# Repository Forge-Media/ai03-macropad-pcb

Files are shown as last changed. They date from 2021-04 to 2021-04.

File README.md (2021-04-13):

# ai03 Inspired Macropad PCB

My attempt at learning and implementing ai03's guide to pcb design for keyboards. The aim of this project is to design and manufacture a simple 3by3 MX style macropad pcb, which actually works. The pcb can then be manufactured and either assembled by hand or by the manufacturer if they provide assembly service.

## Project requirements:

- 9 1U MX-Hotswap switches
- USB-C support
- Atmega32u4 support (MU QFN-44 version)
- Per-key RGB LED (9 LEDs)
- RGB Underglow (4 LEDs)
- ESD and Reverse Bias protection (Fused VCC and +5v)
- QMK support
- VIA support (TBD)

## CAD

KiCad 5.1.9 is used for the pcb design, based on [ai03's guide](https://wiki.ai03.com/books/pcb-design).

**Required KiCad libraries:**

- [ai03's KiCad Type-C library](https://github.com/ai03-2725/Type-C.pretty) (USB-C 2.0 connector)
- [ai03's hybrid footprints](https://github.com/ai03-2725/MX_Alps_Hybrid/tree/master/MX_Only.pretty) (Kailh Hotswap footprints)
- [ai03's random components](https://github.com/ai03-2725/random-keyboard-parts.pretty) (Reset button footprint)
- [ebastler's kicad components](https://github.com/ebastler/kicad-keyboard-parts.pretty) (RGB LEDs footprints and 3D models)

**Optional KiCad libraries:**

- [KiCad included switches](https://kicad.github.io/footprints/Button_Switch_Keyboard) (Solder MX footprints) (Unless 5.1.9 or later)
- [Perigoso's KiCad Keyboard libraries](https://github.com/perigoso/keyswitch-kicad-library) (Alternative MX footprints)
- (TBD)

Autocad, Rhino and Fusion 360 are used for the case design.

## References:

- [ai03's - pcb guide](https://wiki.ai03.com/books/pcb-design)
- [ai03's KiCad library list](https://wiki.ai03.com/books/pcb-design/page/list-of-kicad-keyboard-parts-libraries)
- [33C Discord](https://discord.gg/6fHK4uk)
- [Keyboard Atelier Discord](https://discord.gg/b7vwhHS)
- [QMK Docs](https://beta.docs.qmk.fm/developing-qmk/c-development/compatible_microcontrollers)
- [Hadi's - PCB design series](https://www.youtube.com/channel/UCpWGAJr2AU7LPUwVYbBQZRg/playlists) (Incomplete!)
- [KoBuss' - How we designed a mechanicial keyboard pcb](https://www.youtube.com/watch?v=ezk02GJ9iMs)
- [MrKeebs' - PCB from Scratch with Gondo series](https://www.youtube.com/watch?v=Nk0egpDFqRA)
- [FJ Laboratories Blog](https://www.fjlaboratories.com/)
- (TBD)

## License

MIT License

Copyright (c) 2021 ForgeMedia (Jeremy Paton)

Permission is hereby granted, free of charge, to any person obtaining a copy of this hardware, software, and associated documentation files (the "Product"), to deal in the Product without restriction, including without limitation the rights to use, copy, modify, merge, publish, distribute, sublicense, and/or sell copies of the Product, and to permit persons to whom the Product is furnished to do so, subject to the following conditions:

The above copyright notice and this permission notice shall be included in all copies or substantial portions of the Product.

THE PRODUCT IS PROVIDED "AS IS", WITHOUT WARRANTY OF ANY KIND, EXPRESS OR IMPLIED, INCLUDING BUT NOT LIMITED TO THE WARRANTIES OF MERCHANTABILITY, FITNESS FOR A PARTICULAR PURPOSE AND NONINFRINGEMENT. IN NO EVENT SHALL THE AUTHORS OR COPYRIGHT HOLDERS BE LIABLE FOR ANY CLAIM, DAMAGES OR OTHER LIABILITY, WHETHER IN AN ACTION OF CONTRACT, TORT OR OTHERWISE, ARISING FROM, OUT OF OR IN CONNECTION WITH THE PRODUCT OR THE USE OR OTHER DEALINGS IN THE PRODUCT.

## For the Keyboard Community

You can produce and sell this keyboard design. ForgeMedia (Jeremy Paton) is not liable. Creator attribution is required however, no use of the creator's or 3rd party branding may be utilised in a derivative. This includes logos and brand names.

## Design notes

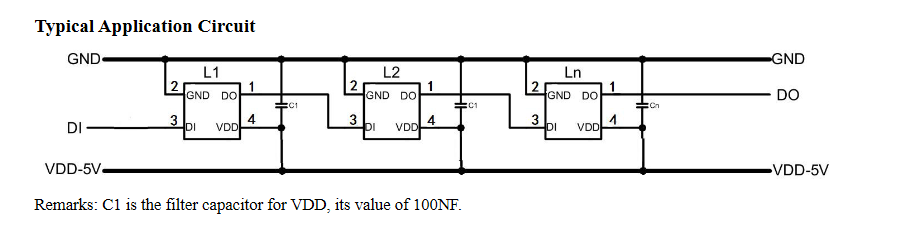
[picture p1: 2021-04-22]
references/specifications/String_RGB_LED_Array_Schematic.png

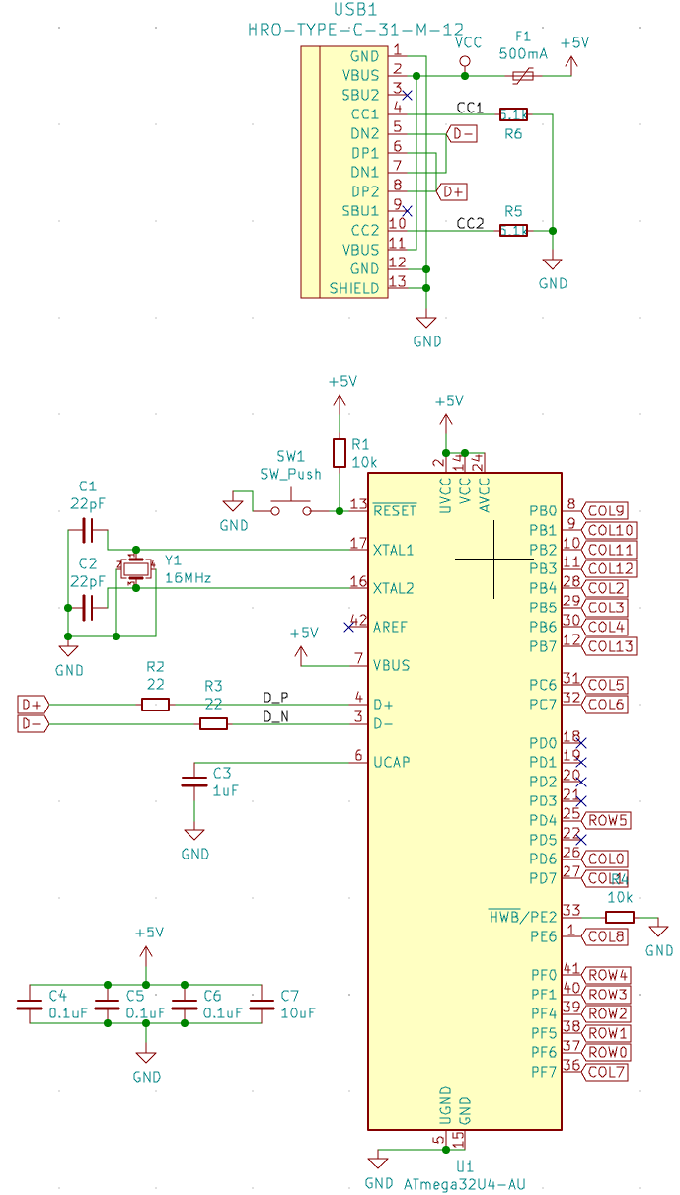
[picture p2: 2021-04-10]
references/reference_images/USB_Type-C_simplified_schematic_alt_2.png

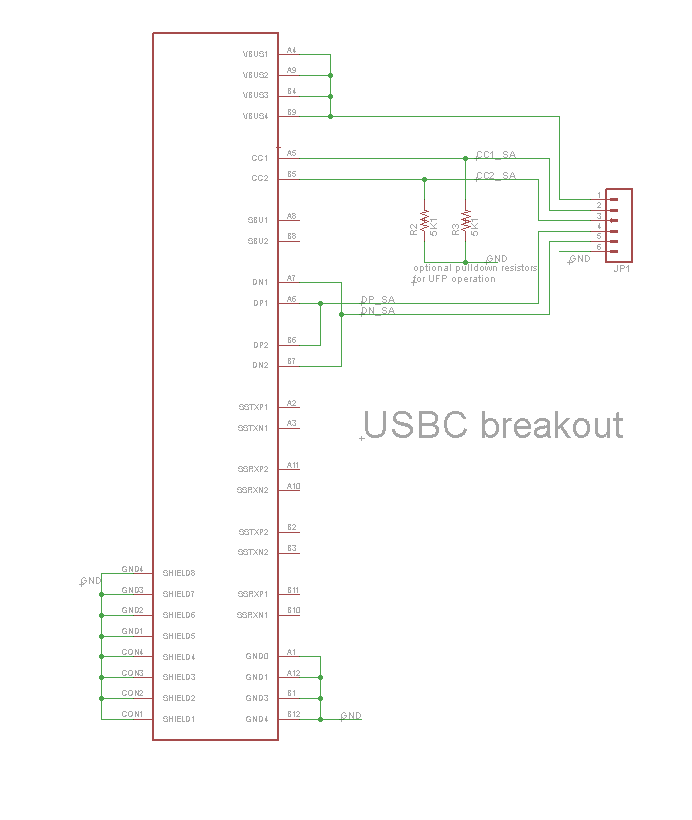
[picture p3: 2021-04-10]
references/reference_images/USB_Type-C_schematic.png

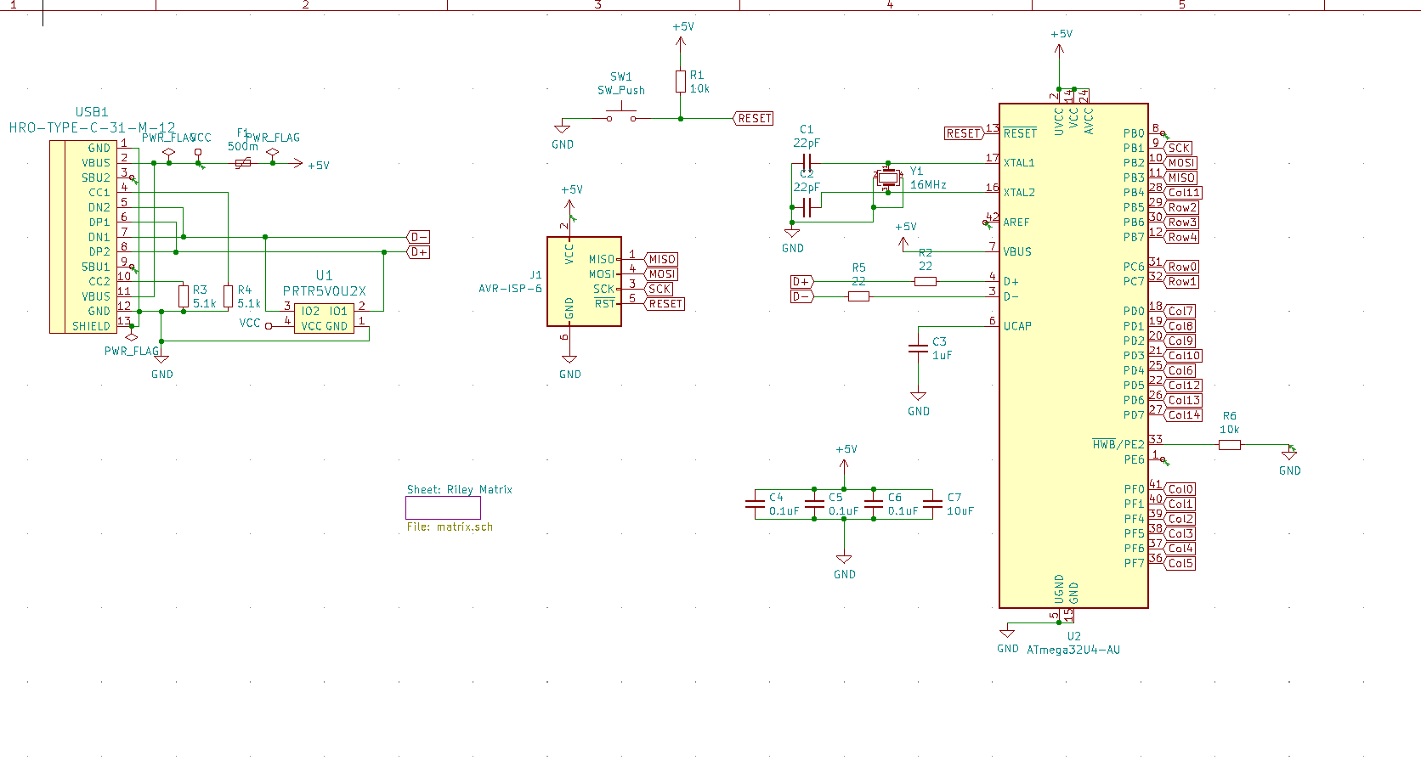
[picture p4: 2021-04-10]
references/reference_images/USB_Type-C_simplified_schematic_alt.png

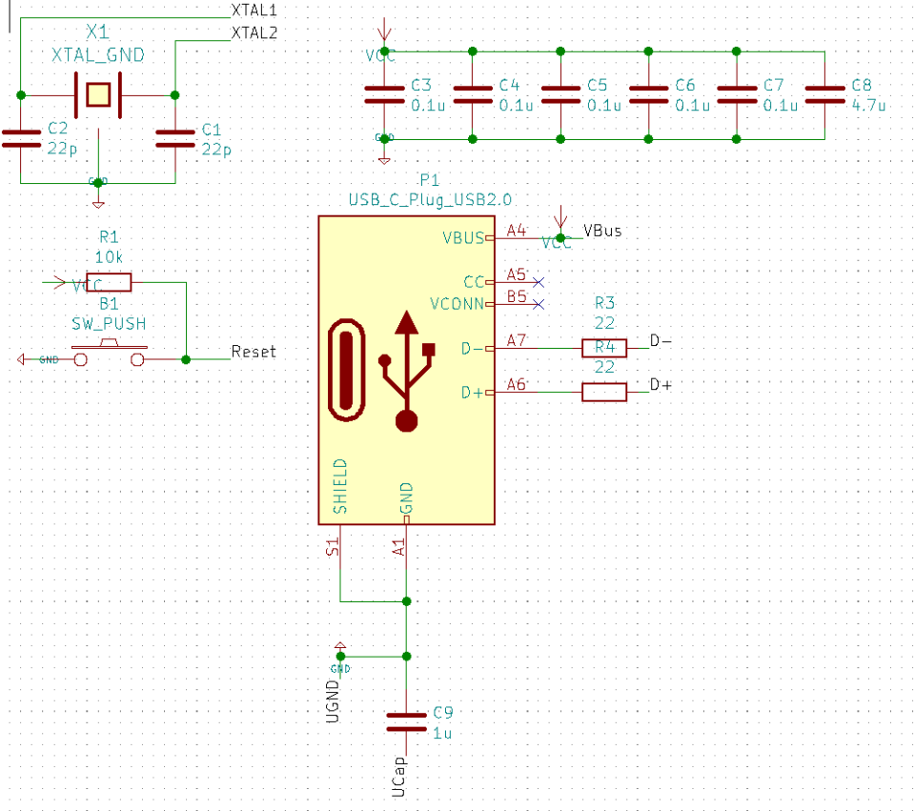
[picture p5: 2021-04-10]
references/reference_images/USB_Type-C_simplified_schematic.png

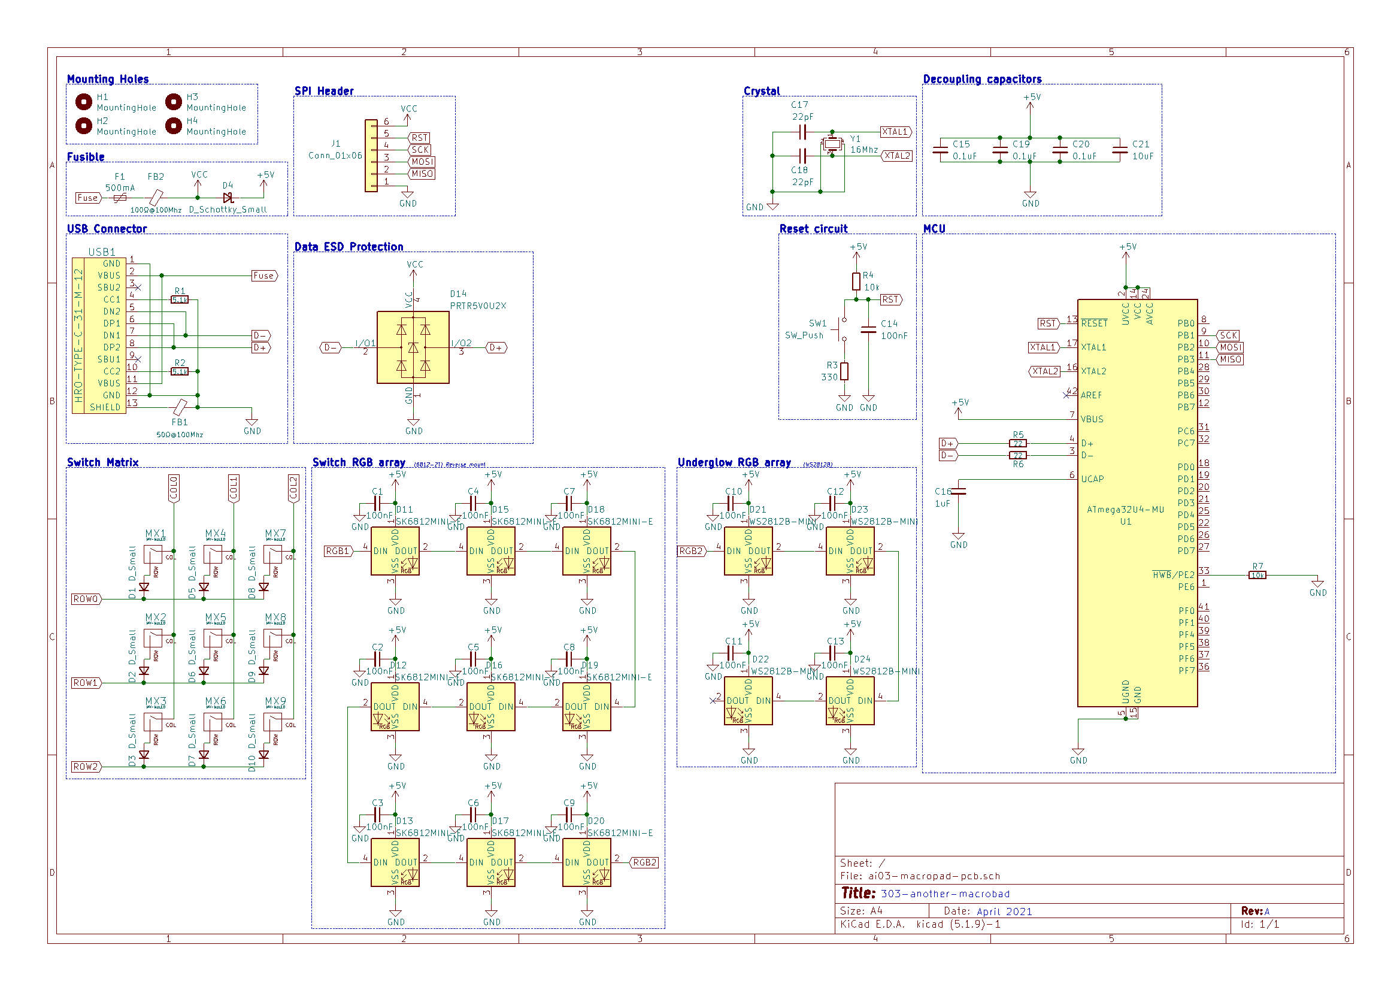
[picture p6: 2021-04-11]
references/schematic_reviews/schematic_rev_a.png

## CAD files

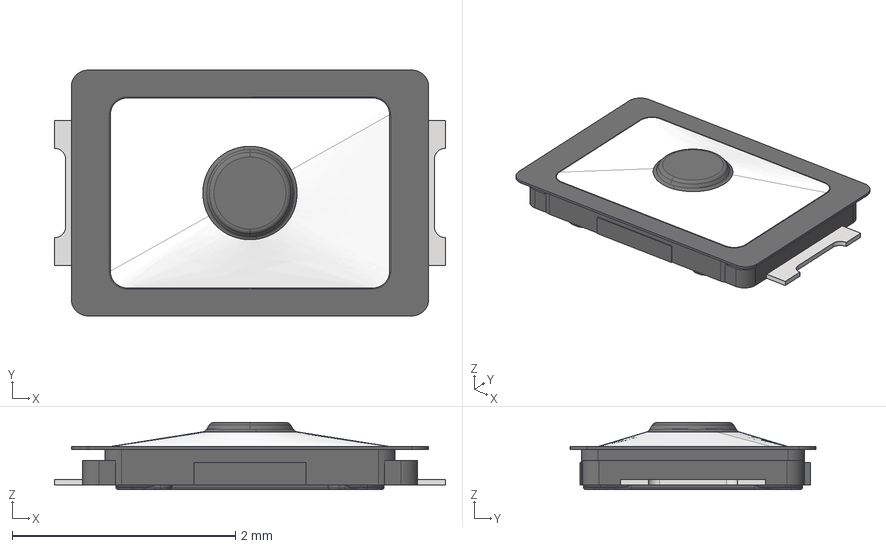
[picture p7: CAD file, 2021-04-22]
3D_models/EVPAWBD40_Solid.step
3.50 x 2.20 x 0.6 mm

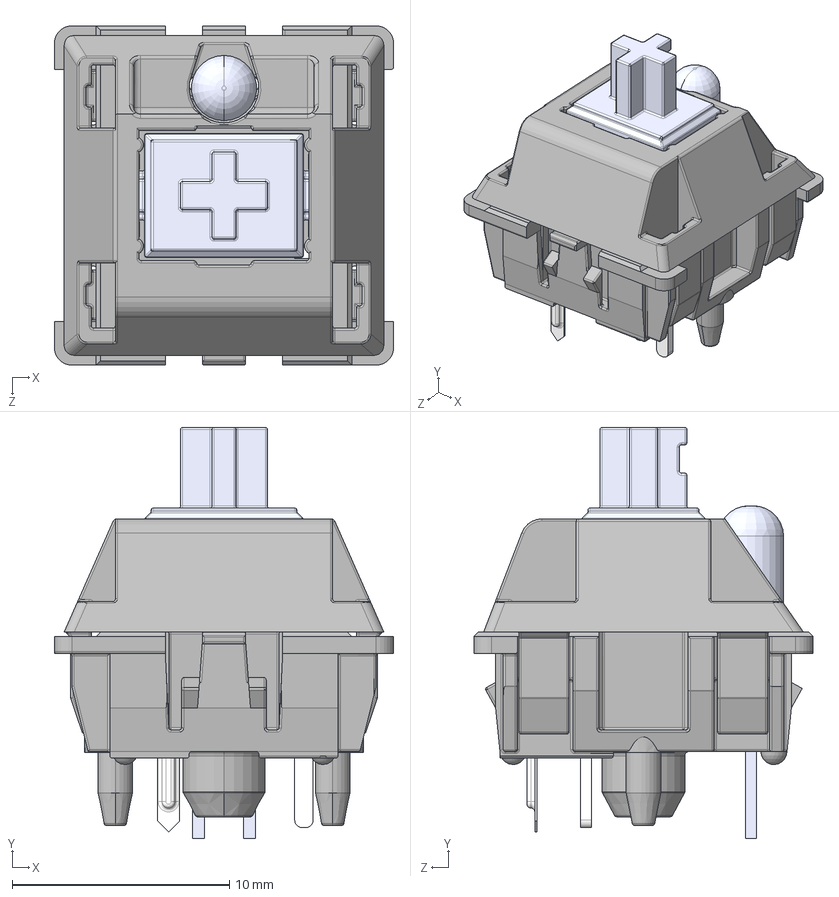
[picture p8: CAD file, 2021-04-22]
3D_models/MX.STEP
15.6 x 18.9 x 15.6 mm
MX 轴 按键′_ü___¨1
MX 轴 轴体áì_¨￠¨__
MX粣 拸簽LEDLEDLED
MX轴 轴体 底部 μ×2__默认_á2____è_
针脚___默认__è_

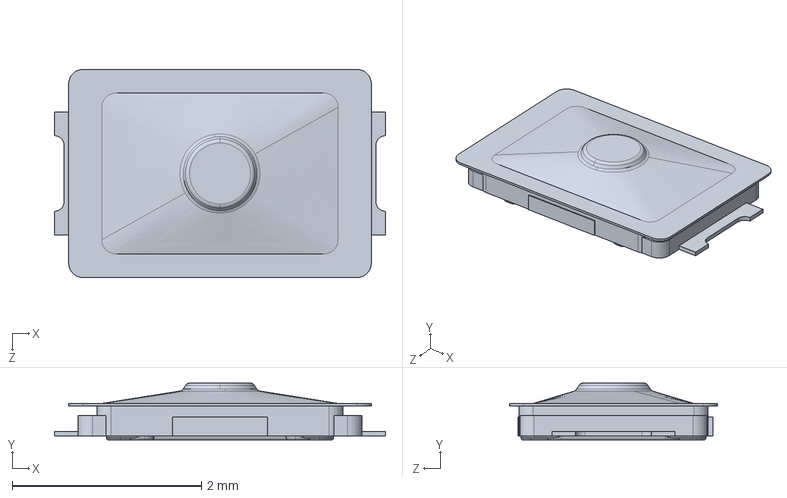
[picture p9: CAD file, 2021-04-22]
3D_models/EVPAWBD40.step
3.50 x 0.6 x 2.20 mm

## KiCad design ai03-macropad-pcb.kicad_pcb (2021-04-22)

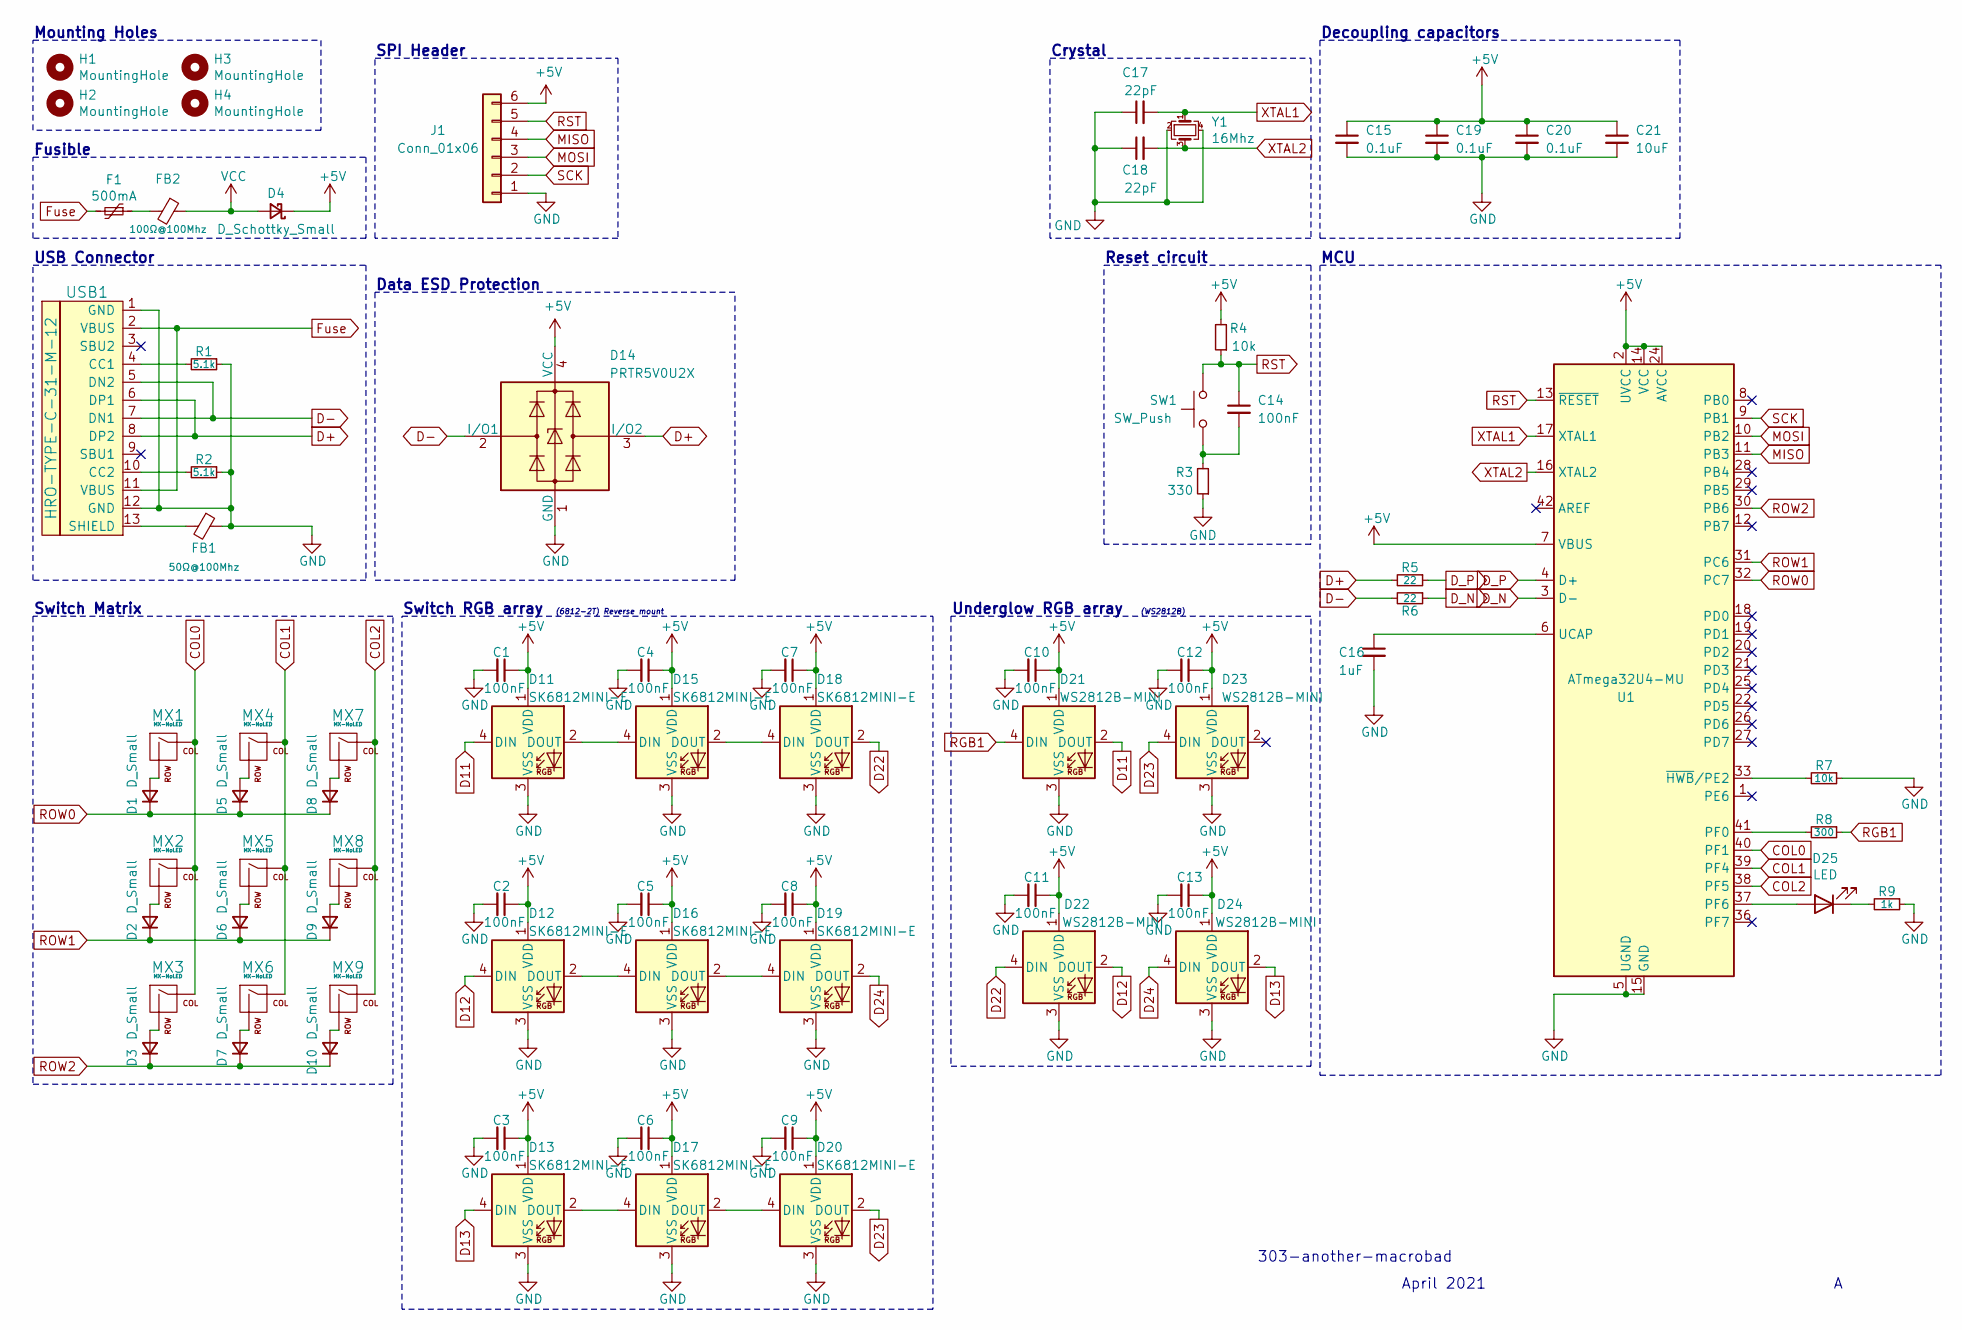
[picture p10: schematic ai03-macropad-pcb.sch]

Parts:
C1, C2, C3, C4, C5, C6, C7, C8, C9, C10, C11, C12, C13, C14: 100nF; C_0603_1608Metric
C15, C19, C20: 0.1uF; C_0603_1608Metric
C16: 1uF; C_0603_1608Metric
C17, C18: 22pF; C_0603_1608Metric
C21: 10uF; C_0603_1608Metric
D1, D2, D3, D5, D6, D7, D8, D9, D10: D_Small; D_SOD-123
D4: D_Schottky_Small; D_SOD-123
D11, D12, D13, D15, D16, D17, D18, D19, D20: SK6812MINI-E; MX_SK6812MINI-E
D14: PRTR5V0U2X; SOT-143
D21, D22, D23, D24: WS2812B-MINI; LED_SK6812MINI_PLCC4_3.5x3.5mm_P1.75mm
D25: LED; LED_0603_1608Metric
F1: 500mA; Fuse_0805_2012Metric
FB1: 50Ω@100Mhz; Fuse_0603_1608Metric
FB2: 100Ω@100Mhz; Fuse_0805_2012Metric
H1, H2, H3, H4: MountingHole; MountingHole_3.2mm_M3_DIN965_Pad
J1: Conn_01x06; JST_SHL_SM06B-SHLS-TF_1x06-1MP_P1.00mm_Horizontal
MX1, MX2, MX3, MX4, MX5, MX6, MX7, MX8, MX9: MX-NoLED; MXOnly-1U-Hotswap-Antishear
R1, R2: 5.1k; R_0603_1608Metric
R3: 330; R_0603_1608Metric
R4, R7: 10k; R_0603_1608Metric
R5, R6: 22; R_0603_1608Metric
R8: 300; R_0603_1608Metric
R9: 1k; R_0603_1608Metric
SW1: SW_Push; SW_SPST_CK_KXT3
U1: ATmega32U4-MU; QFN-44-1EP_7x7mm_P0.5mm_EP5.2x5.2mm
USB1: HRO-TYPE-C-31-M-12; HRO-TYPE-C-31-M-12-Assembly
Y1: 16Mhz; Crystal_SMD_3225-4Pin_3.2x2.5mm

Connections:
+5V: C1.1, C2.1, C3.1, C4.1, C5.1, C6.1, C7.1, C8.1, C9.1, C10.1, C11.1, C12.1, C13.1, C15.1, C19.1, C20.1, C21.1, D4.1 (K), D11.1 (VDD), D12.1 (VDD), D13.1 (VDD), D14.4 (VCC), D15.1 (VDD), D16.1 (VDD), D17.1 (VDD), D18.1 (VDD), D19.1 (VDD), D20.1 (VDD), D21.1 (VDD), D22.1 (VDD), D23.1 (VDD), D24.1 (VDD), J1.6, R4.2, U1.2 (UVCC), U1.7 (VBUS), U1.14 (VCC), U1.24 (AVCC), U1.34 (VCC), U1.44 (AVCC); also elsewhere on the board
COL0: MX1.1 (COL), MX2.1 (COL), MX3.1 (COL), U1.40 (PF1)
COL1: MX4.1 (COL), MX5.1 (COL), MX6.1 (COL), U1.39 (PF4)
COL2: MX7.1 (COL), MX8.1 (COL), MX9.1 (COL), U1.38 (PF5)
D11: D11.4 (DIN), D21.2 (DOUT)
D12: D12.4 (DIN), D22.2 (DOUT)
D13: D13.4 (DIN), D24.2 (DOUT)
D22: D18.2 (DOUT), D22.4 (DIN)
D23: D20.2 (DOUT), D23.4 (DIN)
D24: D19.2 (DOUT), D24.4 (DIN)
D+: D14.3 (I/O2), R5.2, USB1.6 (DP1), USB1.8 (DP2)
D-: D14.2 (I/O1), R6.2, USB1.5 (DN2), USB1.7 (DN1)
D_N: R6.1, U1.3 (D-)
D_P: R5.1, U1.4 (D+)
Fuse: F1.2, USB1.2 (VBUS), USB1.11 (VBUS)
GND: C1.2, C2.2, C3.2, C4.2, C5.2, C6.2, C7.2, C8.2, C9.2, C10.2, C11.2, C12.2, C13.2, C15.2, C16.2, C17.1, C18.1, C19.2, C20.2, C21.2, D11.3 (VSS), D12.3 (VSS), D13.3 (VSS), D14.1 (GND), D15.3 (VSS), D16.3 (VSS), D17.3 (VSS), D18.3 (VSS), D19.3 (VSS), D20.3 (VSS), D21.3 (VSS), D22.3 (VSS), D23.3 (VSS), D24.3 (VSS), FB1.1, J1.1, R1.1, R2.1, R3.1, R7.1, R9.1, U1.5 (UGND), U1.15 (GND), U1.23 (GND), U1.35 (GND), U1.43 (GND), U1.45 (GND), USB1.1 (GND), USB1.12 (GND), Y1.2, Y1.4; also elsewhere on the board
MISO: J1.4, U1.11 (PB3); also elsewhere on the board
MOSI: J1.3, U1.10 (PB2); also elsewhere on the board
unnamed: C14.2, R3.2, SW1.1
unnamed: C16.1, U1.6 (UCAP)
unnamed: D1.2 (A), MX1.2 (ROW)
unnamed: D2.2 (A), MX2.2 (ROW)
unnamed: D3.2 (A), MX3.2 (ROW)
unnamed: D5.2 (A), MX4.2 (ROW)
unnamed: D6.2 (A), MX5.2 (ROW)
unnamed: D7.2 (A), MX6.2 (ROW)
unnamed: D8.2 (A), MX7.2 (ROW)
unnamed: D9.2 (A), MX8.2 (ROW)
unnamed: D10.2 (A), MX9.2 (ROW)
unnamed: D11.2 (DOUT), D15.4 (DIN)
unnamed: D12.2 (DOUT), D16.4 (DIN)
unnamed: D13.2 (DOUT), D17.4 (DIN)
unnamed: D15.2 (DOUT), D18.4 (DIN)
unnamed: D16.2 (DOUT), D19.4 (DIN)
unnamed: D17.2 (DOUT), D20.4 (DIN)
unnamed: D25.1 (K), R9.2
unnamed: D25.2 (A), U1.37 (PF6)
unnamed: F1.1, FB2.2
unnamed: FB1.2, USB1.13 (SHIELD)
unnamed: R1.2, USB1.4 (CC1)
unnamed: R2.2, USB1.10 (CC2)
unnamed: R7.2, U1.33 (~HWB~/PE2)
unnamed: R8.2, U1.41 (PF0)
RGB1: D21.4 (DIN), R8.1
ROW0: D1.1 (K), D5.1 (K), D8.1 (K), U1.32 (PC7)
ROW1: D2.1 (K), D6.1 (K), D9.1 (K), U1.31 (PC6)
ROW2: D3.1 (K), D7.1 (K), D10.1 (K), U1.30 (PB6)
RST: C14.1, J1.5, R4.1, SW1.2, U1.13 (~RESET); also elsewhere on the board
SCK: J1.2, U1.9 (PB1); also elsewhere on the board
VCC: D4.2 (A), FB2.1
XTAL1: C17.2, U1.17 (XTAL1), Y1.1
XTAL2: C18.2, U1.16 (XTAL2), Y1.3

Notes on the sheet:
Data ESD Protection
USB Connector
Fusible
SPI Header
MCU
Reset circuit
Decoupling capacitors
Mounting Holes
Switch Matrix
Switch RGB array
Underglow RGB array
(6812-2T) Reverse mount
(WS2812B)
Crystal
303-another-macrobad
April 2021

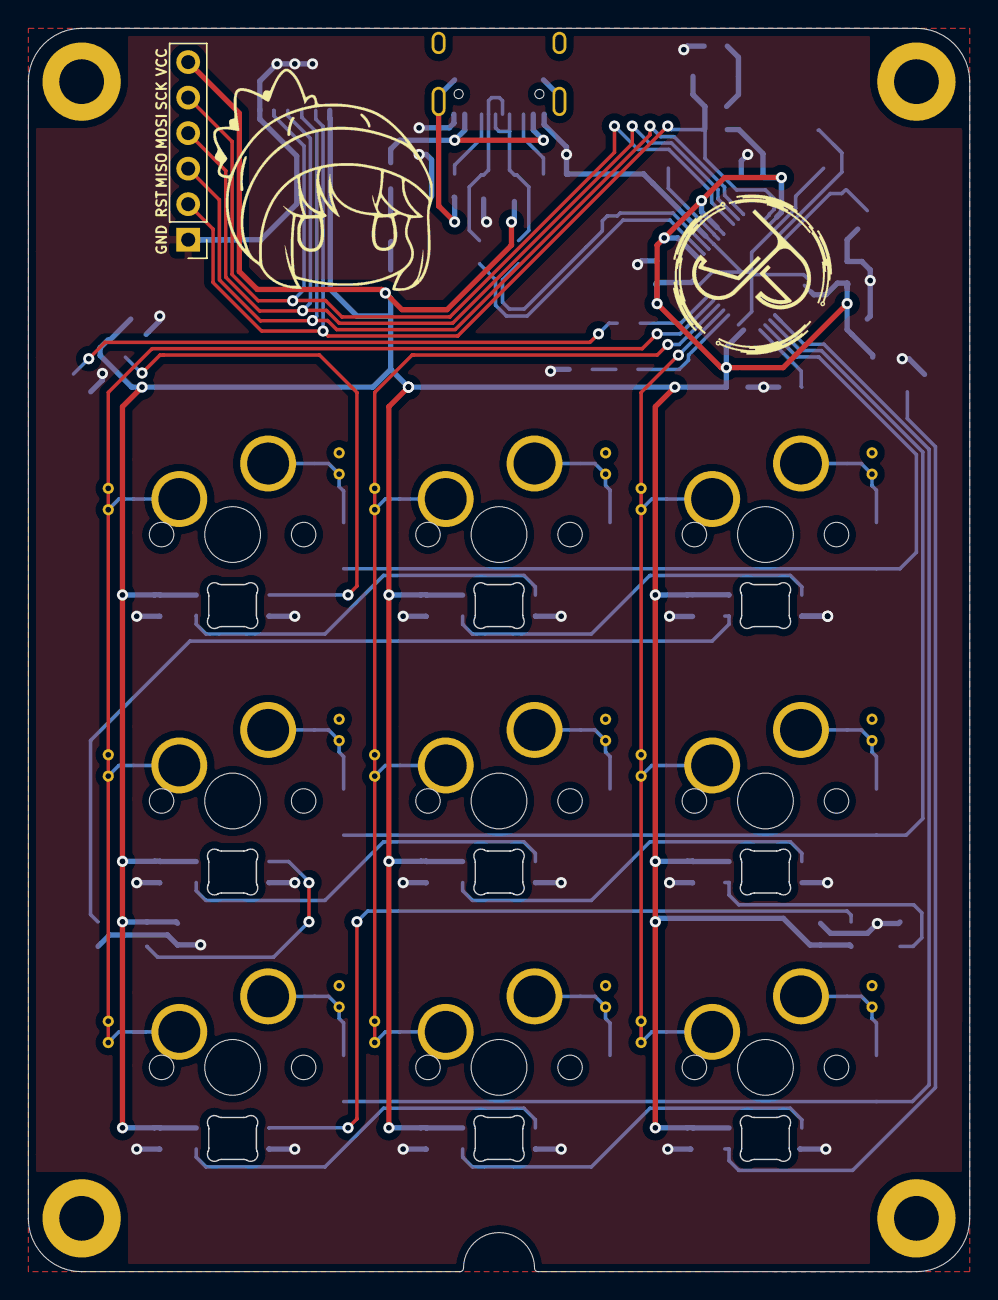
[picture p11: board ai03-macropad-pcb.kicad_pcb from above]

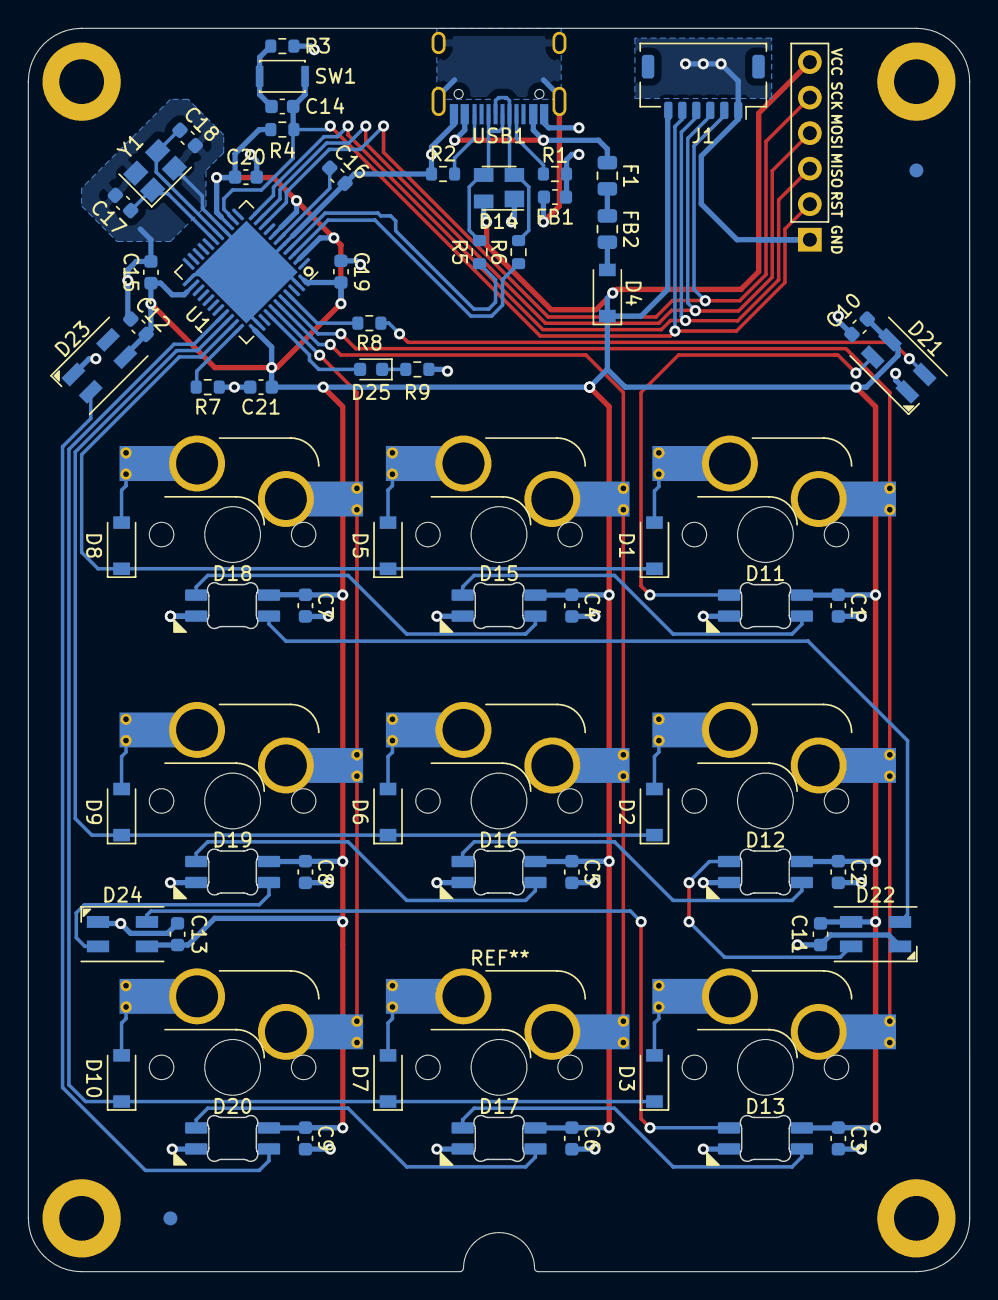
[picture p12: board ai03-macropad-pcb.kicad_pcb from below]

Board: 2 copper layers, 67.3 x 88.9 mm, 77 parts (54 on the bottom side), 52 nets.

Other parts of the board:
J2: ICSP; ICSP-Header

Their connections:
+5V: J2.6; also elsewhere on the board
GND: J2.1; also elsewhere on the board
MISO: J2.3; also elsewhere on the board
MOSI: J2.4; also elsewhere on the board
RST: J2.2; also elsewhere on the board
SCK: J2.5; also elsewhere on the board

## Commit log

2021-04-09 KiCad init
    [ai03-macropad-pcb.kicad_pcb, ai03-macropad-pcb.sch]
2021-04-09 KiCad Library added as sub-modules
2021-04-09 Added project libraries to KiCad
2021-04-09 MCU boilerplate schematic
2021-04-10 USB-C and ESD schematic
    [ai03-macropad-pcb.sch]
2021-04-11 Switch matrix and RGB array
    [ai03-macropad-pcb.sch]
2021-04-11 Footprints and schematic fixes
    [ai03-macropad-pcb.sch]
2021-04-11 Schematic improvements and added libraries
    [ai03-macropad-pcb.sch]
2021-04-13 Routing for switches and RGBs
    [ai03-macropad-pcb.sch]
2021-04-14 Routing of MCU, USB and BUS Lanes
    [ai03-macropad-pcb.kicad_pcb, ai03-macropad-pcb.sch]
2021-04-22 RevA Routing complete
    [EVPAWBD40.step, EVPAWBD40_Solid.step, MX.STEP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]
2021-04-22 RevA DRC check
    [ai03-macropad-pcb.kicad_pcb, ai03-macropad-pcb.sch]
2021-04-22 Gerbers pre-prod
    [ai03-macropad-pcb-B_Cu.gbr, ai03-macropad-pcb-B_Mask.gbr, ai03-macropad-pcb-B_Paste.gbr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]
